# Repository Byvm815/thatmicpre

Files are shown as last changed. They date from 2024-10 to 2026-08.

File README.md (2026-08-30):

# Fork 
1. Slightly reduced the width of the mainboard to fit aluminum cases available on China's Taobao.
2. Adjusted the panel layout height and the positions and sizes of the mounting holes to match the aluminum cases on Taobao.

I also replaced the NC3MBH1 with the NCJ6FA-H, which is compatible with both 6.35mm TRS and XLR connectors. I have fabricated or tested the new mainboard. Anyone interested can fabricate it directly; the design has been work without issues.

During the process, I used That1512 and SSM2019 chips purchased from Taobao, but neither produced an output. Finally, I bought a second-hand AD620 from Taobao for just $0.6, with free shipping, and it worked as expected.

I hope my experience can help others avoid unnecessary trouble.

(I am not good at English, and all of this was translated using ChatGPT.)

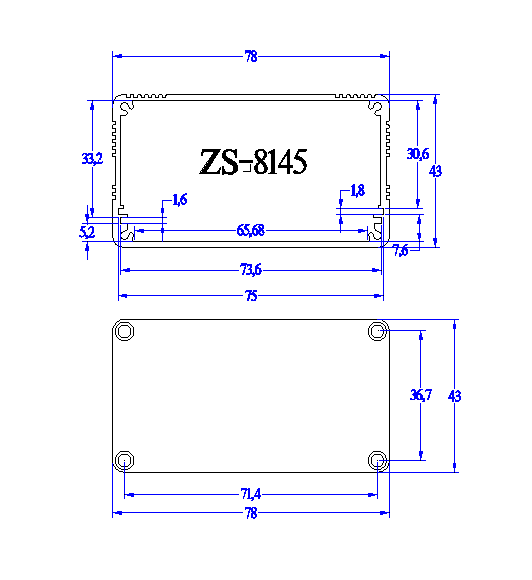
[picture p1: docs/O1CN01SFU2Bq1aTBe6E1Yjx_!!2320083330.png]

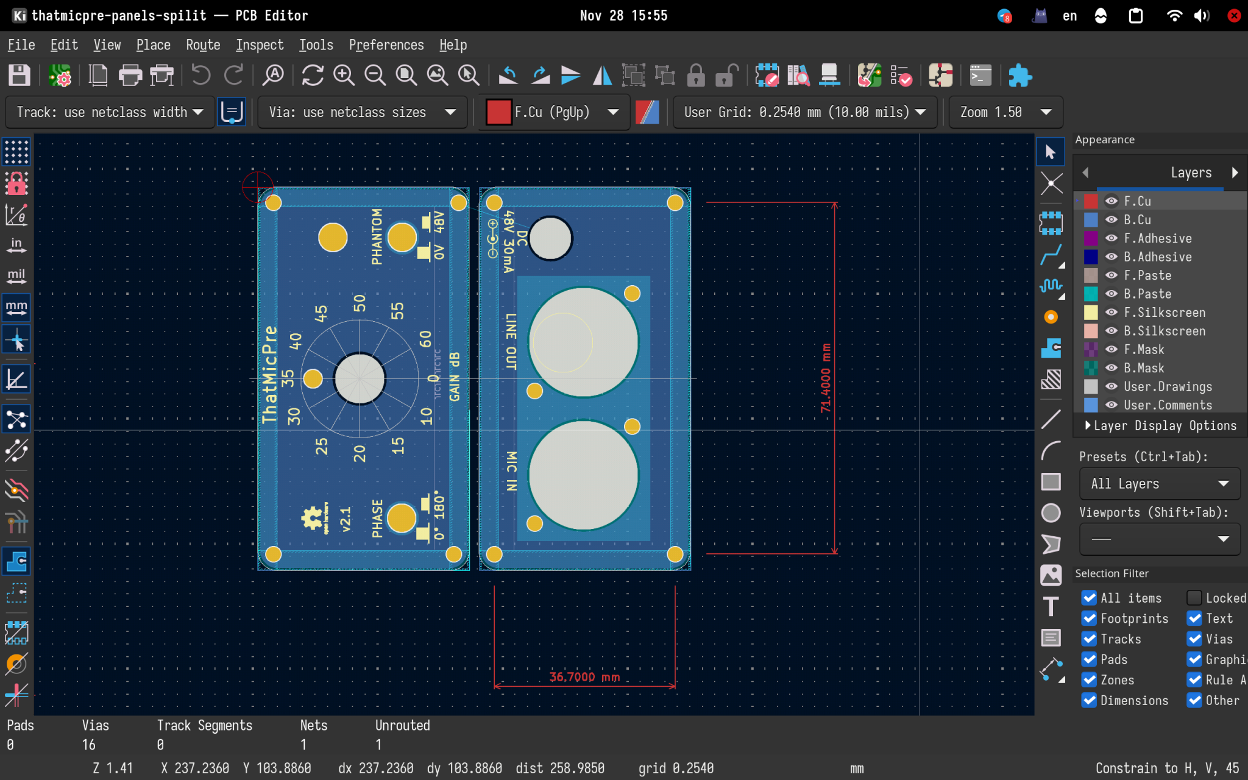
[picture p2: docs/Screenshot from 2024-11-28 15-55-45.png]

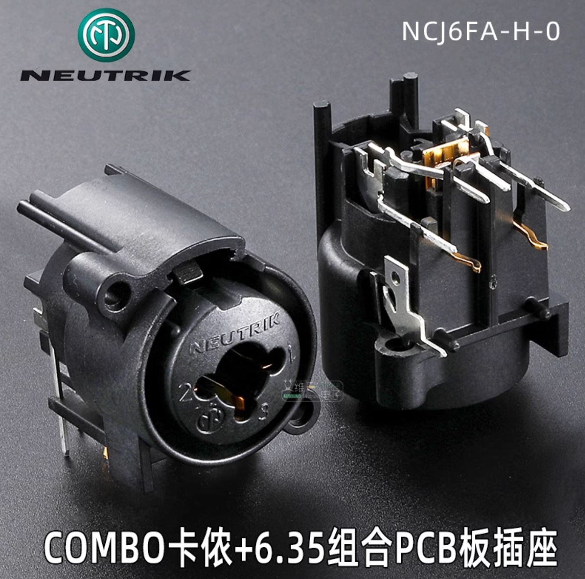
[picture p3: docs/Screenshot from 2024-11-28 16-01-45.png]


=====

ThatMicPre
=====
A simple, high-quality DIY microphone pre-amplifier with switched gain.

The background for this project was that I needed a simple but good microphone preamp for doing acoustic measurements. I needed a switched gain to be able to reproduce the gain setting in a more predictable way than what is possible with a potmeter. I could not find any existing DIY designs, so I decided to make one.

The design is based on the excellent [THAT1510 or THAT1512](https://thatcorp.com/that-1510-1512-low-noise-high-performance-audio-preamplifiers/) preamp ICs. It is also compatible with [SSM2019](https://www.analog.com/en/products/ssm2019.html) or [INA217](https://www.ti.com/product/INA217). I have followed all THAT's datasheets and app-notes to implement a robust, best-practice design.

A goal was to use simple through-hole parts that I and other DIYers usually have in our parts drawer. So there are no additional IC's or voltage regulators for example, it just uses simple transistors, capacitors and zener diodes for supply filtering and regulation. I selected affordable switches and connectors to keep cost down. Many parts can be substituted without sacrificing performance.

There are two versions of this design, one suited for a desktop encolsure with gain switch on top, and one suited for a rack-mount enclosure with gain switch on the front.

There is a separate PCB project in the panels folder that contains PCB layout for front and back panels that fits the 1455K120x case. Since it is copper-clad on the inside, it makes for a nice shielded box.

This is an open-source project released under CC-BY-SA-4.0 license. It basically means you can use it as you want as long as you share modifications under the same license, and attribute back to this project. See [LICENSE.txt](../blob/master/LICENSE.txt) for details.

See discussion of this project in this [DIYAudio thread.](https://www.diyaudio.com/forums/equipment-and-tools/356317-thatmicpre-source-mic-preamp.html) If you decide to build this pre-amplifier, please post results of your build there.

Specifications
-----
* Microphone preamplifier with switched gain and 48V phantom power.
* XLR input and output connectors.
* Phantom power on/off switch.
* Phase invert switch.
* Gains (dB): 0, 10, 15, 20, 25, 30, 35, 40, 45, 50, 55, 60.
* Gain deviation from nominal: Max +/-0.5dB using R12-series resistors.
* Frequency response: 0/-3dB from 10Hz to 100kHz for all gain settings.
* Input impedance: 2.0kohm differential (1kHz)
* Impedance balanced output, output impedance 200ohm (1kHz)
* Max output level: 20dBu at 0.1% THD (1kHz).
* THD+N less than 0.005% at 1kHz at 18dBu output level for all gain settings (20-20kHz BW).
* 48V DC power supply required, 30mA max. 
  * (Will operate with lower voltage DC power supplies with reduced phantom voltage and max output level).
* PCB dimensions 75mm x 120mm, fits the [Hammond 1455K120x](https://www.hammfg.com/part/1455K1201) enclosure.
  * Desktop version has gain switch on top of enclosure for easy access.
  * Rack version has gain switch on front for easy mounting in a rack enclosure.

Photos
-----
#### Desktop version
Photo of desktop Desktop with panels

Photo of desktop pcb Desktop PCB photo
(PCBA credit jsenderatx on diyaudio)

#### Rack version
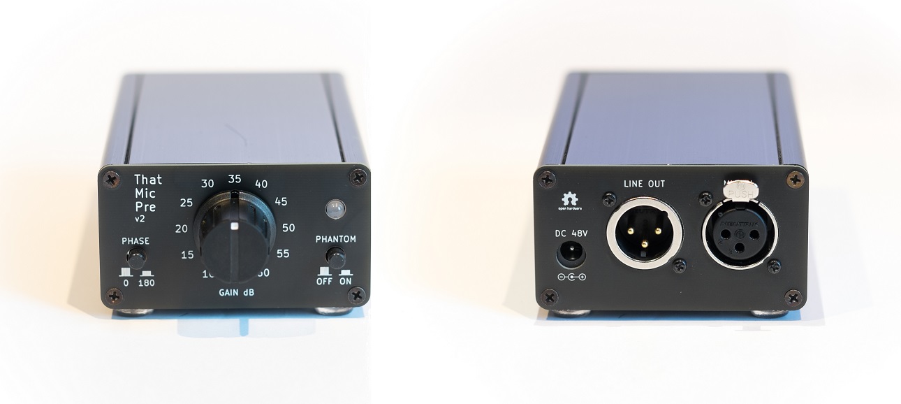
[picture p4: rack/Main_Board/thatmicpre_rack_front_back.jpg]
Photo of rack Rack with panels


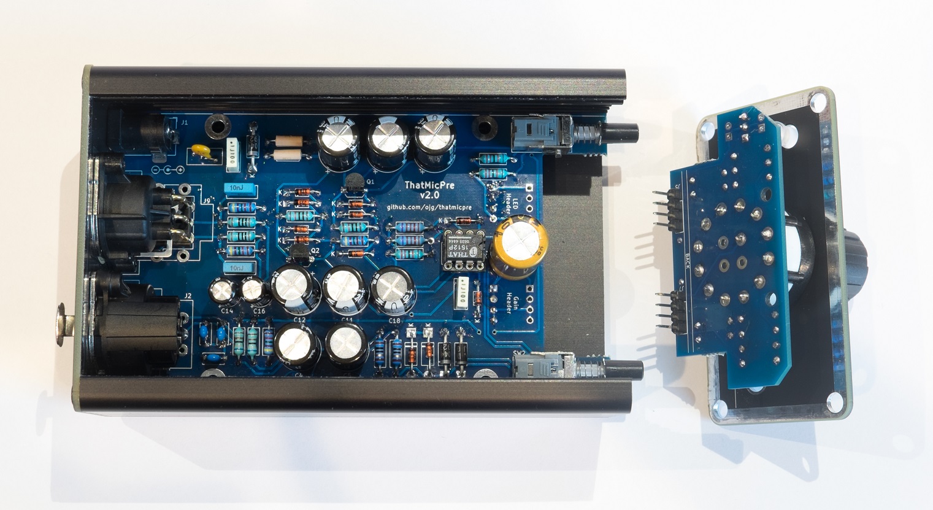
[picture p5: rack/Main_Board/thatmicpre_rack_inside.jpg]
Photo of rack pcb Rack PCB photo


The rack version has a PCB where one part separates. This part contains the gain resistors and switch.
It mounts at a right angle to the main PCB with two angled female headers underneath main PCB. See BOM.

## Bill of Materials
Nicely formatted BOM is in the plots folder for [desktop version](https://htmlpreview.github.io/?https://github.com/ojg/thatmicpre/blob/master/desktop/plots/thatmicpre_bom.html)
and [rack version](https://htmlpreview.github.io/?https://github.com/ojg/thatmicpre/blob/master/rack/plots/thatmicpre_v2_bom.html).

Thanks to the [InteractiveHtmlBom project](https://github.com/openscopeproject/InteractiveHtmlBom).

Schematic
-----
#### Desktop version
Schematic
#### Rack version
Schematic

Measurements
-----
### Output noise vs gain
20-22kHz BW un-wtd, 150ohm source impedance.
Note: Theoretical minimum EIN with 150ohm source impedance is -130.4dBu.

| Gain(dB) | THAT1510<br />Output Noise (dBu) | THAT1510<br />EIN (dBu) | THAT1512<br />Output Noise (dBu) | THAT1512<br />EIN (dBu) |
| --- | --- | --- |--- | --- |
| 0 | -98.5 | -98.5 | -102.4 | -102.4 |
| 10 | -98.2 | -108.2 | -102.0 | -112.0 |
| 15 | -97.8 | -112.8 | -101.3 | -116.3 |
| 20 | -96.8 | -116.8 | -100.0 | -120.0 |
| 25 | -95.6 | -120.6 | -98.0 | -123.0 |
| 30 | -93.2 | -123.2 | -95.2 | -125.2 |
| 35 | -89.8 | -124.8 | -91.5 | -126.5 |
| 40 | -86.8 | -126.8 | -87.3 | -127.3 |
| 45 | -82.6 | -127.6 | -82.8 | -127.8 |
| 50 | -77.8 | -127.8 | -78.1 | -128.1 |
| 55 | -73.1 | -128.1 | -73.3 | -128.3 |
| 60 | -68.3 | -128.3 | -68.6 | -128.6 |

### Frequency Response
#### THAT1510 with 1% R12 resistors
Frequency response
#### THAT1512 with 1% R96 resistors
Frequency response

### THD+N vs Frequency
#### THAT1510
THDN vs frequency
#### THAT1512
THDN vs frequency

### THD+N vs Amplitude
#### THAT1510
THDN vs amplitude
#### THAT1512
THDN vs amplitude

### Common Mode Rejection Ratio
#### THAT1510
CMRR
#### THAT1512
CMRR

### Bandpass Noise Level
Note no measureable hum.
#### THAT1510
Bandpass
#### THAT1512
Bandpass

---

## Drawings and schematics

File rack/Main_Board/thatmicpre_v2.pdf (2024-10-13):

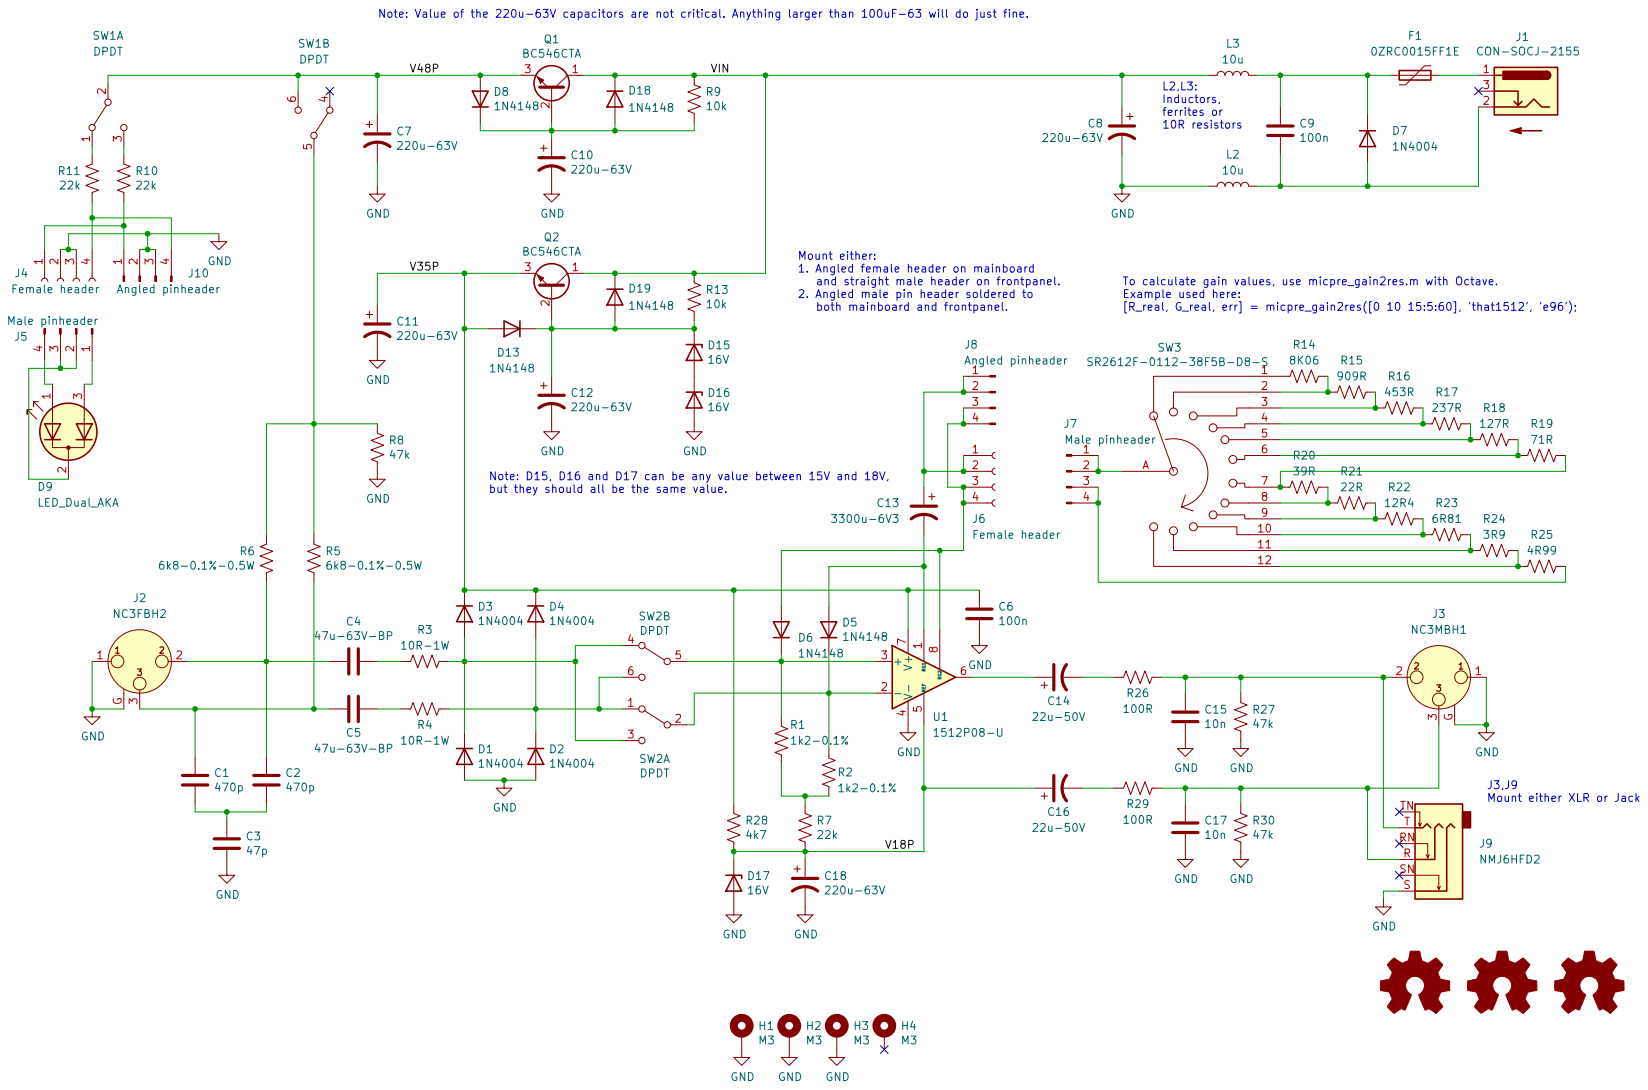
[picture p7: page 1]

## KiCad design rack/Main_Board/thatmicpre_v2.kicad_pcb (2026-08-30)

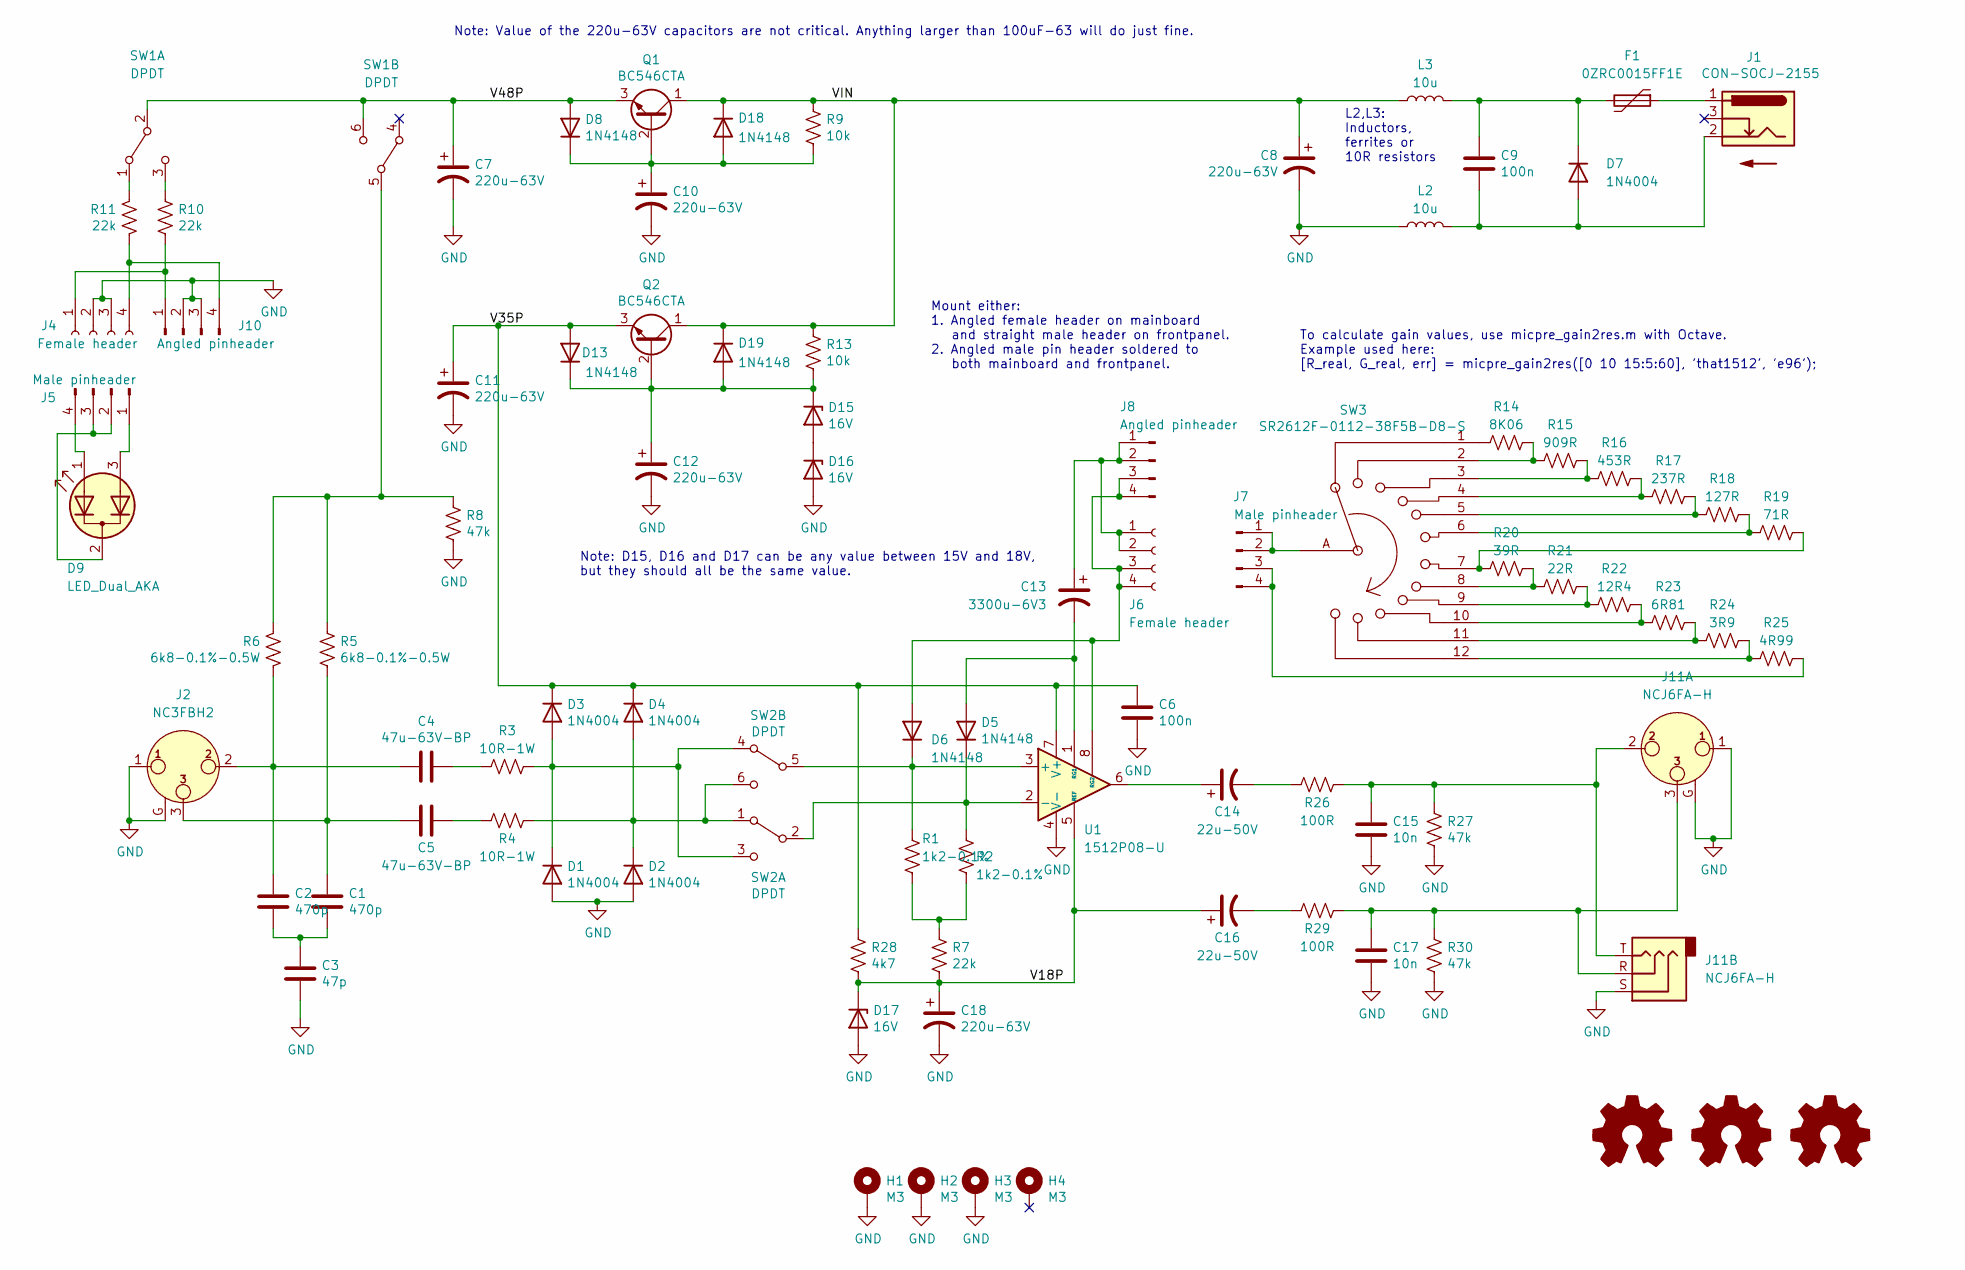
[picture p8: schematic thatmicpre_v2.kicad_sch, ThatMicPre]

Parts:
C1, C2: 470p; C_Disc_D5.0mm_W2.5mm_P5.00mm; Mfr Part Nr FG28C0G2A471JNT0
C3: 47p; C_Disc_D5.0mm_W2.5mm_P5.00mm; Mfr Part Nr FG28C0G2A470JNT0
C4, C5: 47u-63V-BP; C_Radial_D10.0mm_H16.0mm_P5.00mm; Mfr Part Nr UVP1J470MPD
C6, C9: 100n; C_Rect_L7.2mm_W3.0mm_P5.00mm_FKS2_FKP2_MKS2_MKP2; Mfr Part Nr R82EC3100AA70J
C7, C8, C10, C11, C12, C18: 220u-63V; CP_Radial_D10.0mm_P5.00mm; Mfr Part Nr UPW1J221MPD
C13: 3300u-6V3; CP_Radial_D10.0mm_P5.00mm; Mfr Part Nr UFW0J332MPD
C14, C16: 22u-50V; CP_Radial_D6.3mm_P2.50mm; Mfr Part Nr UEP1V220MED
C15, C17: 10n; C_Rect_L7.2mm_W3.0mm_P5.00mm_FKS2_FKP2_MKS2_MKP2; Mfr Part Nr PHE426DJ5100JR05
D1, D2, D3, D4, D7: 1N4004; D_DO-41_SOD81_P10.16mm_Horizontal; Mfr Part Nr 1N4004GP
D5, D6, D8, D13, D18, D19: 1N4148; D_DO-34_SOD68_P7.62mm_Horizontal; Mfr Part Nr 1N4148
D9: LED_Dual_AKA; LED_D5.0mm-3; Mfr Part Nr WP59EGW
D15, D16, D17: 16V; D_DO-34_SOD68_P7.62mm_Horizontal; Mfr Part Nr BZX55B16
F1: 0ZRC0015FF1E; Fuse_BelFuse_0ZRE0005FF_L8.3mm_W3.8mm; Mfr Part Nr 0ZRC0015FF1E
H1, H2, H3, H4: M3; MountingHole_3.2mm_M3_Pad
J1: CON-SOCJ-2155; BarrelJack_Horizontal; Mfr Part Nr CON-SOCJ-2155
J2: NC3FBH2; Jack_XLR_Neutrik_NC3FBH2_Horizontal; Mfr Part Nr NC3FBH2
J4, J6: Female header; PinSocket_1x04_P2.54mm_Horizontal; Mfr Part Nr SSQ-104-02-T-S-RA
J5, J7: Male pinheader; PinHeader_1x04_P2.54mm_Vertical; Mfr Part Nr TSW-104-07-T-S
J8, J10: Angled pinheader; PinHeader_1x04_P2.54mm_Vertical; Mfr Part Nr TSW-104-08-F-S-RA
J11: NCJ6FA-H; Jack_XLR-6.35mm_Neutrik_NCJ6FA-H_Horizontal
L2, L3: 10u; L_Axial_L5.3mm_D2.2mm_P10.16mm_Horizontal_Vishay_IM-1; Mfr Part Nr 78F100J-TR-RC
LOGO1: Logo_Open_Hardware_Small; OSHW-Symbol_6.7x6mm_Copper
LOGO2: Logo_Open_Hardware_Small; Symbol_CC-Attribution_CopperTop_Small
LOGO3: Logo_Open_Hardware_Small; Symbol_CreativeCommons_CopperTop_Type2_Small
LOGO4: SYM_Arrow_Normal; Symbol_Barrel_Polarity
Q1, Q2: BC546CTA; TO-92_Inline_Wide; Mfr Part Nr BC546CTA
R1, R2: 1k2-0.1%; R_Axial_DIN0207_L6.3mm_D2.5mm_P10.16mm_Horizontal; Mfr Part Nr YR1B1K21CC
R3, R4: 10R-1W; R_Axial_DIN0411_L9.9mm_D3.6mm_P15.24mm_Horizontal; Mfr Part Nr CPF110R000FEB14
R5, R6: 6k8-0.1%-0.5W; R_Axial_DIN0309_L9.0mm_D3.2mm_P12.70mm_Horizontal; Mfr Part Nr CMF556K8100BEEK
R7, R10, R11: 22k; R_Axial_DIN0207_L6.3mm_D2.5mm_P10.16mm_Horizontal; Mfr Part Nr MBB02070C2202FCT00
R8, R27, R30: 47k; R_Axial_DIN0207_L6.3mm_D2.5mm_P10.16mm_Horizontal; Mfr Part Nr MBB02070C4702FCT00
R9, R13: 10k; R_Axial_DIN0207_L6.3mm_D2.5mm_P10.16mm_Horizontal; Mfr Part Nr MBB02070C1002FCT00
R14: 8K06; R_Axial_DIN0207_L6.3mm_D2.5mm_P10.16mm_Horizontal; Mfr Part Nr MFR50SFTE52-8K06
R15: 909R; R_Axial_DIN0207_L6.3mm_D2.5mm_P10.16mm_Horizontal; Mfr Part Nr MFR50SFTE52-909R
R16: 453R; R_Axial_DIN0207_L6.3mm_D2.5mm_P10.16mm_Horizontal; Mfr Part Nr MFR50SFTE52-453R
R17: 237R; R_Axial_DIN0207_L6.3mm_D2.5mm_P10.16mm_Horizontal; Mfr Part Nr MFR50SFTE52-237R
R18: 127R; R_Axial_DIN0207_L6.3mm_D2.5mm_P10.16mm_Horizontal; Mfr Part Nr MFR50SFTE52-127R
R19: 71R; R_Axial_DIN0207_L6.3mm_D2.5mm_P10.16mm_Horizontal; Mfr Part Nr MFR50SFTE52-71R
R20: 39R; R_Axial_DIN0207_L6.3mm_D2.5mm_P10.16mm_Horizontal; Mfr Part Nr MFR50SFTE52-39R
R21: 22R; R_Axial_DIN0207_L6.3mm_D2.5mm_P10.16mm_Horizontal; Mfr Part Nr MFR50SFTE52-22R
R22: 12R4; R_Axial_DIN0207_L6.3mm_D2.5mm_P10.16mm_Horizontal; Mfr Part Nr MFR50SFTE52-12R4
R23: 6R81; R_Axial_DIN0207_L6.3mm_D2.5mm_P10.16mm_Horizontal; Mfr Part Nr MFR50SFTE52-6R81
R24: 3R9; R_Axial_DIN0207_L6.3mm_D2.5mm_P10.16mm_Horizontal; Mfr Part Nr MFR50SFTE52-3R9
R25: 4R99; R_Axial_DIN0207_L6.3mm_D2.5mm_P10.16mm_Horizontal; Mfr Part Nr MFR50SFTE52-4R99
R26, R29: 100R; R_Axial_DIN0207_L6.3mm_D2.5mm_P10.16mm_Horizontal; Mfr Part Nr MFR50SFTE52-100R
R28: 4k7; R_Axial_DIN0207_L6.3mm_D2.5mm_P10.16mm_Horizontal; Mfr Part Nr MBB02070C4701FCT00
SW1, SW2: DPDT; SW_PBH2UEESNPNAGX; Mfr Part Nr PBH2UEESNPNAGX
SW3: SR2612F-0112-38F5B-D8-S; LORINCK1049; Mfr Part Nr SR2612F-0112
U1: 1512P08-U; DIP-8_W7.62mm; Mfr Part Nr 1512P08-U

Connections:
/V18P: C16.1, C18.1, D17.1 (K), R7.2, R28.2, U1.5 (REF)
/V35P: C6.1, C11.1, D3.1 (K), D4.1 (K), D13.2 (A), Q2.3 (E), R28.1, U1.7 (V+)
/V48P: C7.1, D8.2 (A), Q1.3 (E), SW1.2 (B), SW1.6 (C)
/VIN: C8.1, D18.1 (K), D19.1 (K), L3.1, Q1.1 (C), Q2.1 (C), R9.1, R13.1
GND: C3.2, C6.2, C7.2, C8.2, C10.2, C11.2, C12.2, C15.2, C17.2, C18.2, D1.2 (A), D2.2 (A), D16.2 (A), D17.2 (A), H1.1, H2.1, H3.1, J2.1, J2.G, J4.2, J4.3, J10.2, J10.3, J11.1, J11.G, J11.S, L2.1, R8.2, R27.2, R30.2, U1.4 (V-); also elsewhere on the board
unnamed: C1.1, C5.1, J2.3, R5.2
unnamed: C1.2, C2.2, C3.1
unnamed: C2.1, C4.1, J2.2, R6.2
unnamed: C4.2, R3.2
unnamed: C5.2, R4.2
unnamed: C14.1, U1.6
unnamed: C14.2, R26.2
unnamed: C15.1, J11.2, J11.T, R26.1, R27.1
unnamed: C16.2, R29.2
unnamed: C17.1, J11.3, J11.R, R29.1, R30.1
unnamed: D1.1 (K), D3.2 (A), R3.1, SW2.3 (C), SW2.4 (A)
unnamed: D2.1 (K), D4.2 (A), R4.1, SW2.1 (A), SW2.6 (C)
unnamed: C13.2, D5.2 (A), U1.1 (RG1)
unnamed: D5.1 (K), R2.1, SW2.2 (B), U1.2 (-)
unnamed: D6.2 (A), J6.3, J6.4, J8.3, J8.4, U1.8 (RG2)
unnamed: D6.1 (K), R1.1, SW2.5 (B), U1.3 (+)
unnamed: C9.2, D7.2 (A), J1.2, L2.2
unnamed: C9.1, D7.1 (K), F1.2, L3.2
unnamed: D9.1 (A1), J5.4
unnamed: D9.3 (A2), J5.1
unnamed: D9.2 (K), J5.2, J5.3
unnamed: C12.1, D13.1 (K), D15.1 (K), D19.2 (A), Q2.2 (B), R13.2
unnamed: D15.2 (A), D16.1 (K)
unnamed: C10.1, D8.1 (K), D18.2 (A), Q1.2 (B), R9.2
unnamed: F1.1, J1.1
unnamed: C13.1, J6.1, J6.2, J8.1, J8.2
unnamed: J7.1, J7.2, SW3.A
unnamed: J7.3, J7.4, R25.2
unnamed: J4.1, J10.1, R10.2
unnamed: J4.4, J10.4, R11.2
unnamed: R1.2, R2.2, R7.1
unnamed: R14.1, R15.2, SW3.2
unnamed: R14.2, SW3.1
unnamed: R15.1, R16.2, SW3.3
unnamed: R16.1, R17.2, SW3.4
unnamed: R17.1, R18.2, SW3.5
unnamed: R18.1, R19.2, SW3.6
unnamed: R19.1, R20.2, SW3.7
unnamed: R20.1, R21.2, SW3.8
unnamed: R21.1, R22.2, SW3.9
unnamed: R22.1, R23.2, SW3.10
unnamed: R23.1, R24.2, SW3.11
unnamed: R24.1, R25.1, SW3.12
unnamed: R11.1, SW1.1 (A)
unnamed: R10.1, SW1.3 (C)
unnamed: R5.1, R6.1, R8.1, SW1.5 (B)

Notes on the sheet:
To calculate gain values, use micpre_gain2res.m with Octave. Example used here: [R_real, G_real, err] = micpre_gain2res([0 10 15:5:60], 'that1512', 'e96');
Mount either: 1. Angled female header on mainboard and straight male header on frontpanel. 2. Angled male pin header soldered to both mainboard and frontpanel.
L2,L3: Inductors, ferrites or 10R resistors
Note: Value of the 220u-63V capacitors are not critical. Anything larger than 100uF-63 will do just fine.
Note: D15, D16 and D17 can be any value between 15V and 18V, but they should all be the same value.

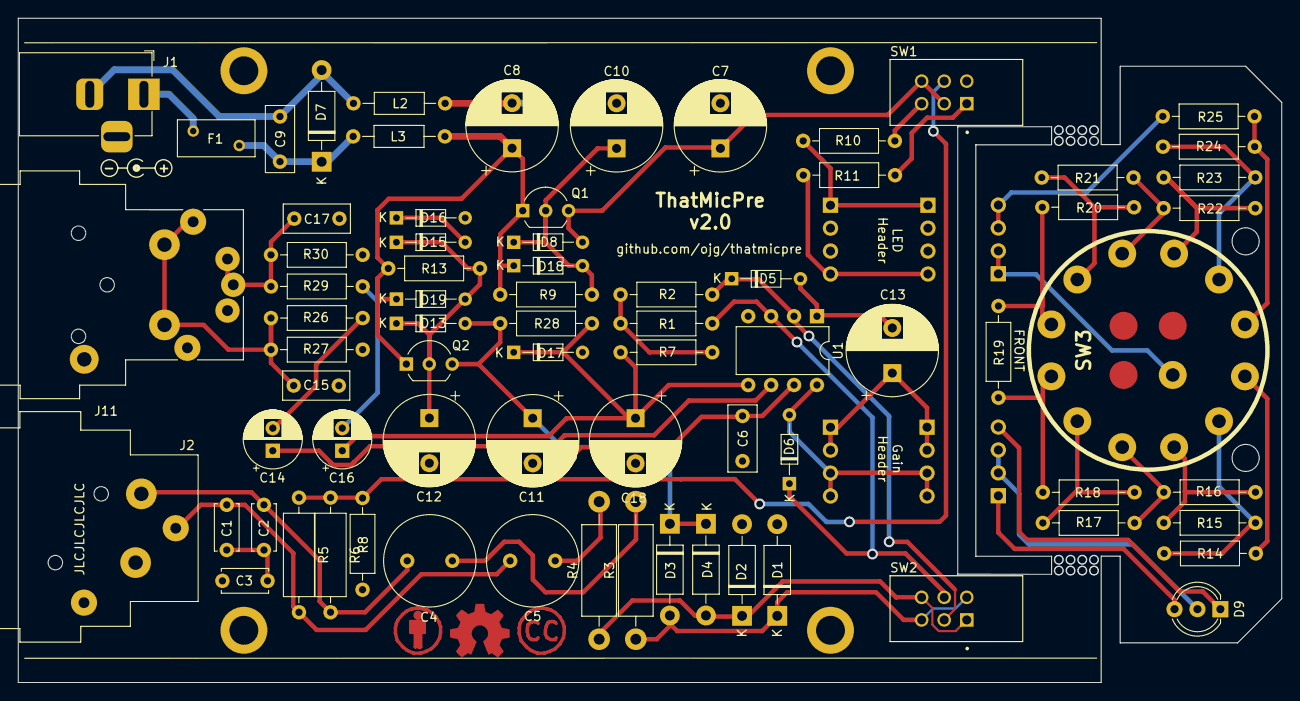
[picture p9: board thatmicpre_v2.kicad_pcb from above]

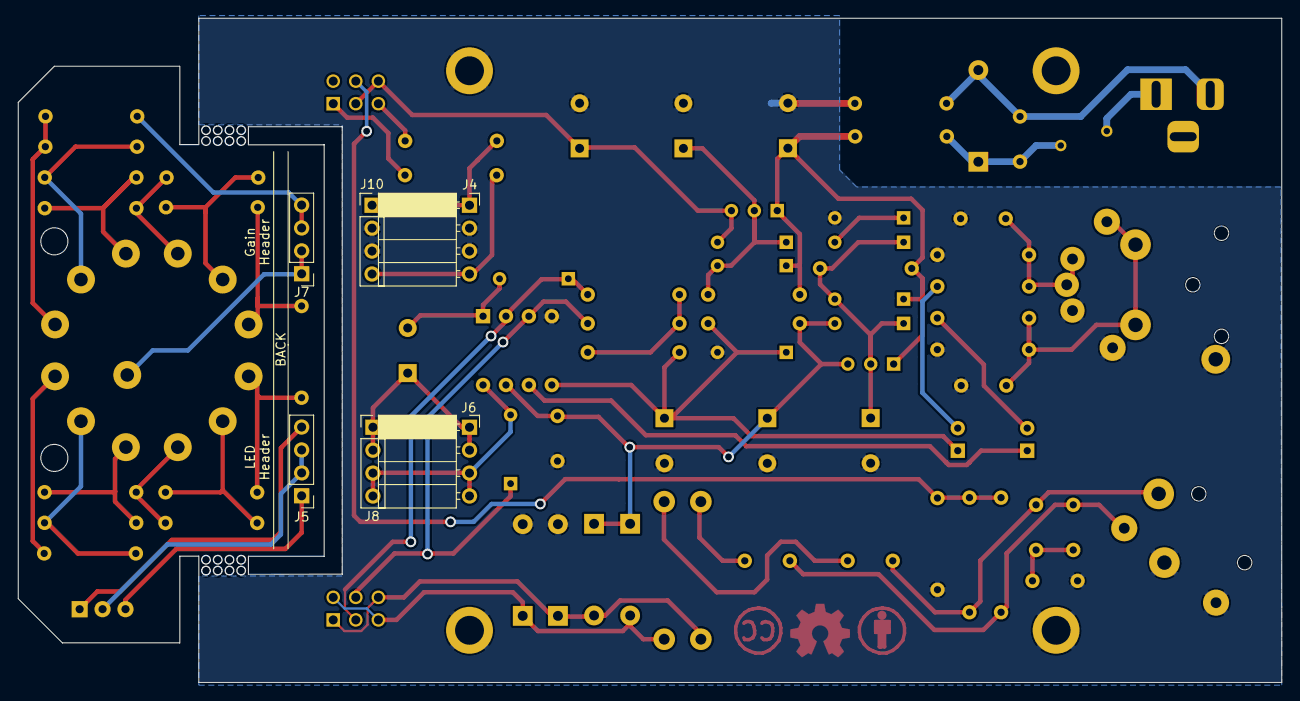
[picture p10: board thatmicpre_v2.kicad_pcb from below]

Board: 2 copper layers, 140.0 x 73.6 mm, 88 parts (6 on the bottom side), 51 nets.

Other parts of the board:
H1#2, H1#3, H1#4: M3; MountingHole_3.2mm_M3_Pad

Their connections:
GND: H1#2.1, H1#3.1; also elsewhere on the board

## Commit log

2024-09-05 The motherboard width is compatible with the new case
    [thatmicpre_v2.kicad_pcb]
2024-09-05 Move the hole of panels up by 1mm. For the new case
    [thatmicpre-panels.kicad_pcb]
2024-09-05 The mounting hole spacing for the panels is adapted to the new case
    [thatmicpre-panels.kicad_pcb]
2024-09-09 Add panels-spilit PCB
    [thatmicpre-panels-spilit.kicad_pcb]
2024-09-11 Fix the bug where the hole positions and panel move in opposite directions, and optimize the size of the mounting holes
    [thatmicpre-panels-spilit.kicad_pcb]
2024-10-13 change NC3MBH1 to be NCJ6FA-H
    [thatmicpre_v2.kicad_pcb, thatmicpre_v2.kicad_sch]
2024-10-16 Remove the unnecessary solid lines, and optimize the panel labels.
    [thatmicpre-panels-spilit.kicad_pcb]
2024-10-16 Change diameter of GND pad to be 5.2mm
    [thatmicpre_v2.kicad_pcb]
2024-10-16 Change motherboard width to be 73.6mm
    [thatmicpre_v2.kicad_pcb]
2024-10-17 Fix the bug where the panel has a 1mm error(maked1 ). Move the hole of panels up by 1mm, and optimize the panel labels.
    [thatmicpre-panels-spilit.kicad_pcb]
2024-10-17 optimize the panel labels
    [thatmicpre-panels-spilit.kicad_pcb]
2024-11-19 optimize the panel labels. Make room for adding a power switch
    [thatmicpre-panels-spilit.kicad_pcb]
2024-11-19 Fixed bug, NCJ6FA-H where 1-2pin connections were interchanged
    [thatmicpre_v2.kicad_pcb, thatmicpre_v2.kicad_sch]
2024-12-05 Modify the footprints of 0.5W and 1W resistors
    [thatmicpre_v2.kicad_pcb, thatmicpre_v2.kicad_sch]
